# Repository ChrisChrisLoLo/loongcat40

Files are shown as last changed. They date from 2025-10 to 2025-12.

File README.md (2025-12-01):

# loongcat40
A 4x10 gasket mounted keyboard featuring a large OLED. A culmination of 5 years of learning.

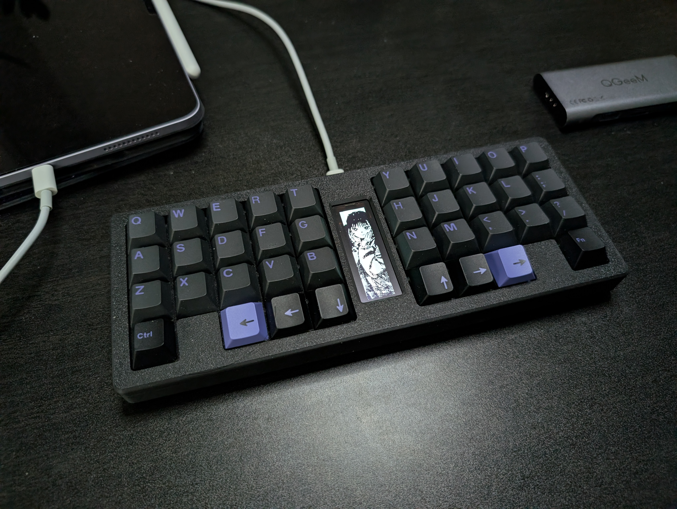
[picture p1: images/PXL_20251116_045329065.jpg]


## status
- v0.1 pcbs have been produced but not yet tested.
- v0.0 pcbs have been produced. v0.0 has been been tested.
  - The keyboard largely works, though GPIO20 requires an external pullup resistor. This may have been due to the rp2040 dev board I was using.

## about
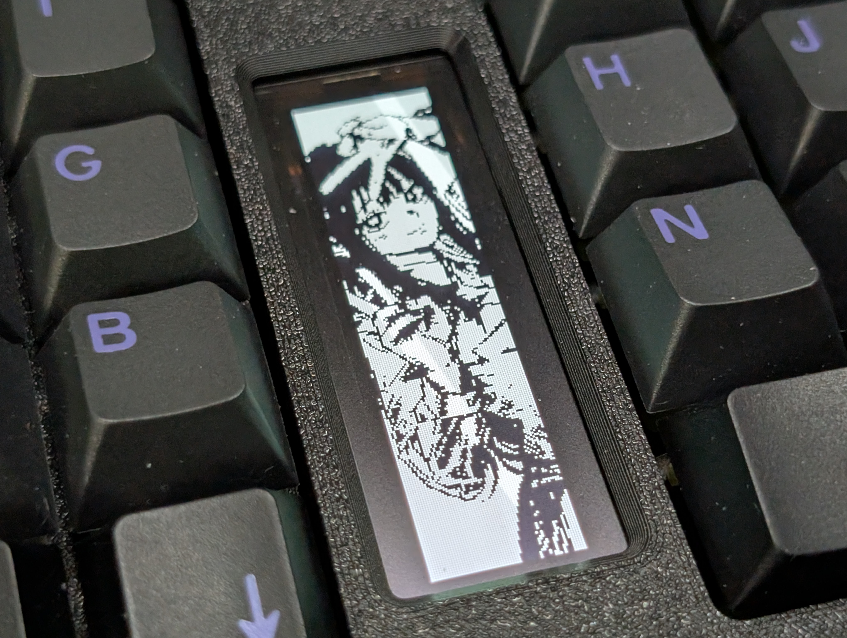
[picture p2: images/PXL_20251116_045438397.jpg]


## case
All of the case files you need can be found in the `case` directory.

## pcb
You can find the PCB source files in the `pcb` folder. The BOM files can be found in this folder.

## directory structure
- `case`
    You can find the files you need in this folder to print out a case for the keyboard
- `drafts`
    Stores any KLE or intermediate information used in making the case
- `pcb`
    Kicad project relating to the project

## BOM
- 1 PCB
- 40 hotswap sockets
- 40 diodes
- 1 2.08" OLED LCD (SH1122)
- 3mm poron gasket strips (80mm x 3mm x 4mm)
- 1 Raspberry Pi Pico 1
- 3D printed parts
  - 4 TPU oled standoffs
    - used to make sure that the oled is aligned when soldering
  - 2 PLA plates
  - 1 PLA case bottom
  - 1 PLA casetop
- 12 5mm M2 screws
- 4 rubber bumpons
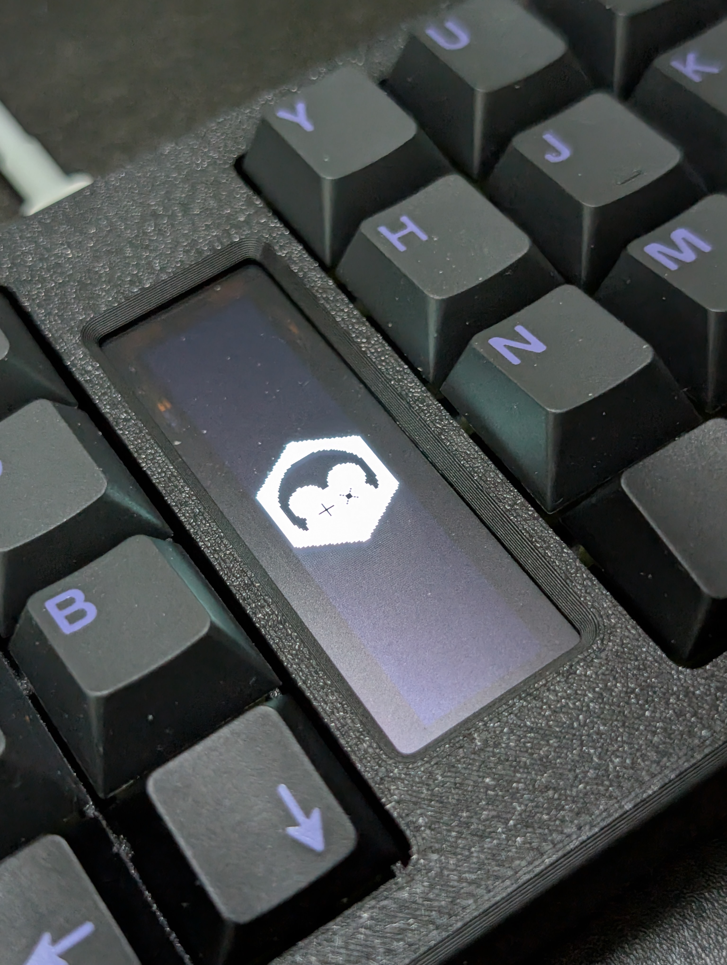
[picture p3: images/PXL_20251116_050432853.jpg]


## assembly
- Assemble the PCB without the oled
  - the Pico should be soldered via castellated pins. Male pin headers should _not_ be used 
- Put the 4 TPU oled standoffs onto the oled module. These standoffs will help align the oled
- Solder the oled to the pcb. The oled module should be on the other side of the board such that it's on the opposite side 
- Put the poron gaskets onto the plate
- Put the keys through the plate and onto the PCB
- Put the PCB onto the top of the case
- Put the bottom of the case on
- Screw in the bottom of the case
  - Note that screwing the screws for the first time may take some force, as the screws will be threading the plastic of the top
- Put bumpers on the bottom of the case
- Done!

## firmware
You can find the QMK firmware for this project here: https://github.com/ChrisChrisLoLo/qmk_firmware/tree/loongcat40

## acknowledgements

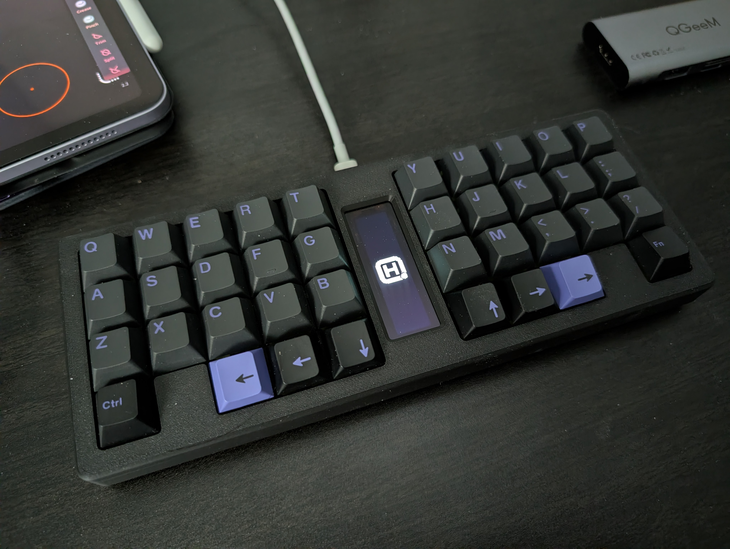
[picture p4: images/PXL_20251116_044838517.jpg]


Thank you to [NextPCB](https://www.nextpcb.com/?code=ChristianLo) and all of my Github Sponsors for sponsoring and supporting this project!

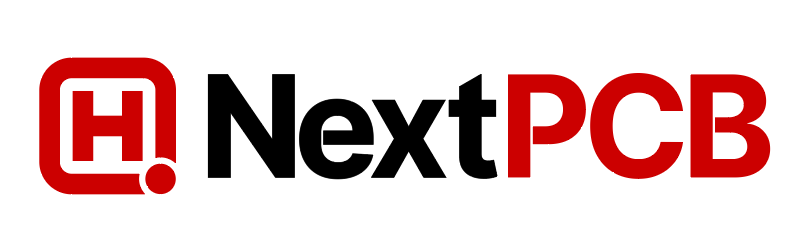
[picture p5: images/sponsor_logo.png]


Big thank you to [@suh_ga](https://x.com/suh_ga) for the fantastic artwork used and displayed on this keyboard! Please check her out at https://twitter.com/suh_ga!

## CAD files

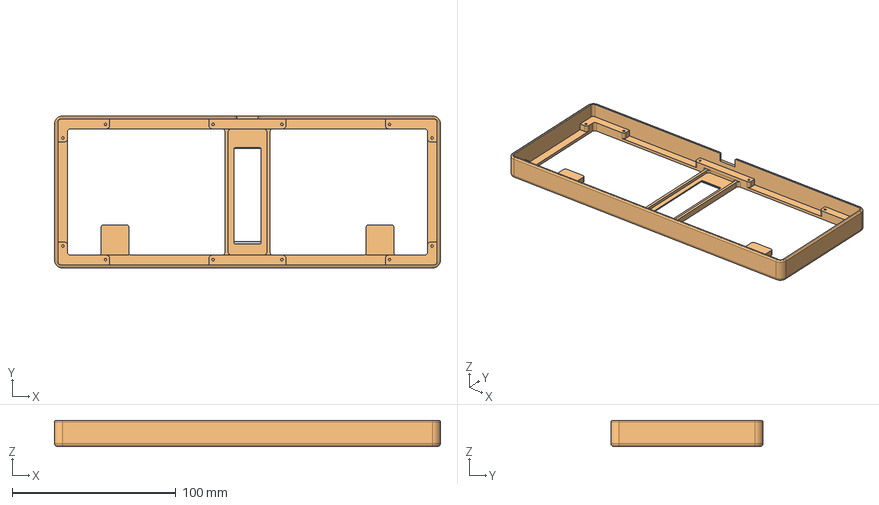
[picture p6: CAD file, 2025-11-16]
case/loongcat40.FCStd
235.9 x 93.0 x 16.0 mm
TopOledModCover
TopLcdModCover

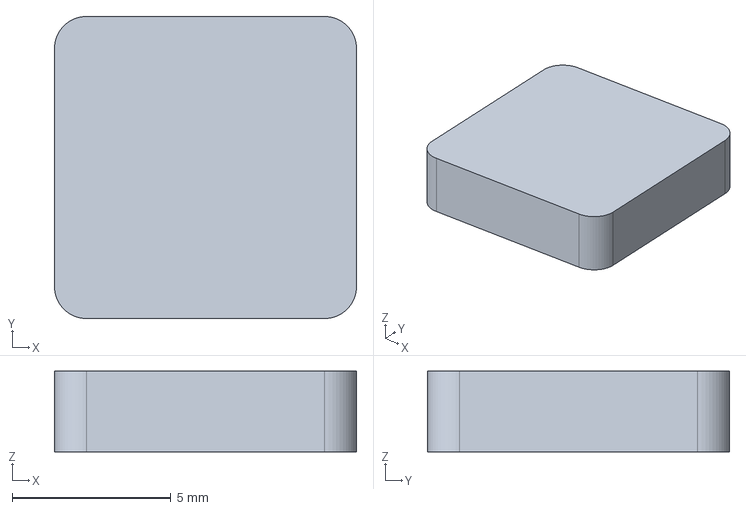
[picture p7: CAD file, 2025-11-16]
case/lcd_solder_jig_standoff.FCStd
9.50 x 9.50 x 2.54 mm

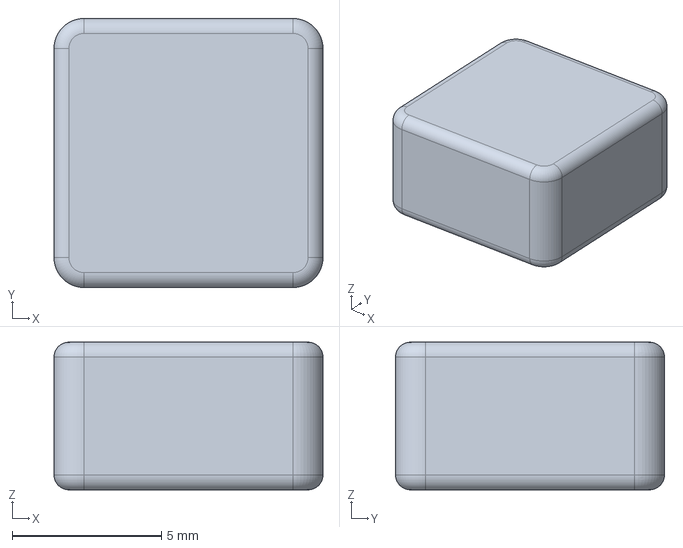
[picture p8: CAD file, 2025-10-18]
case/oled_standoff.FCStd
9.00 x 9.00 x 4.94 mm

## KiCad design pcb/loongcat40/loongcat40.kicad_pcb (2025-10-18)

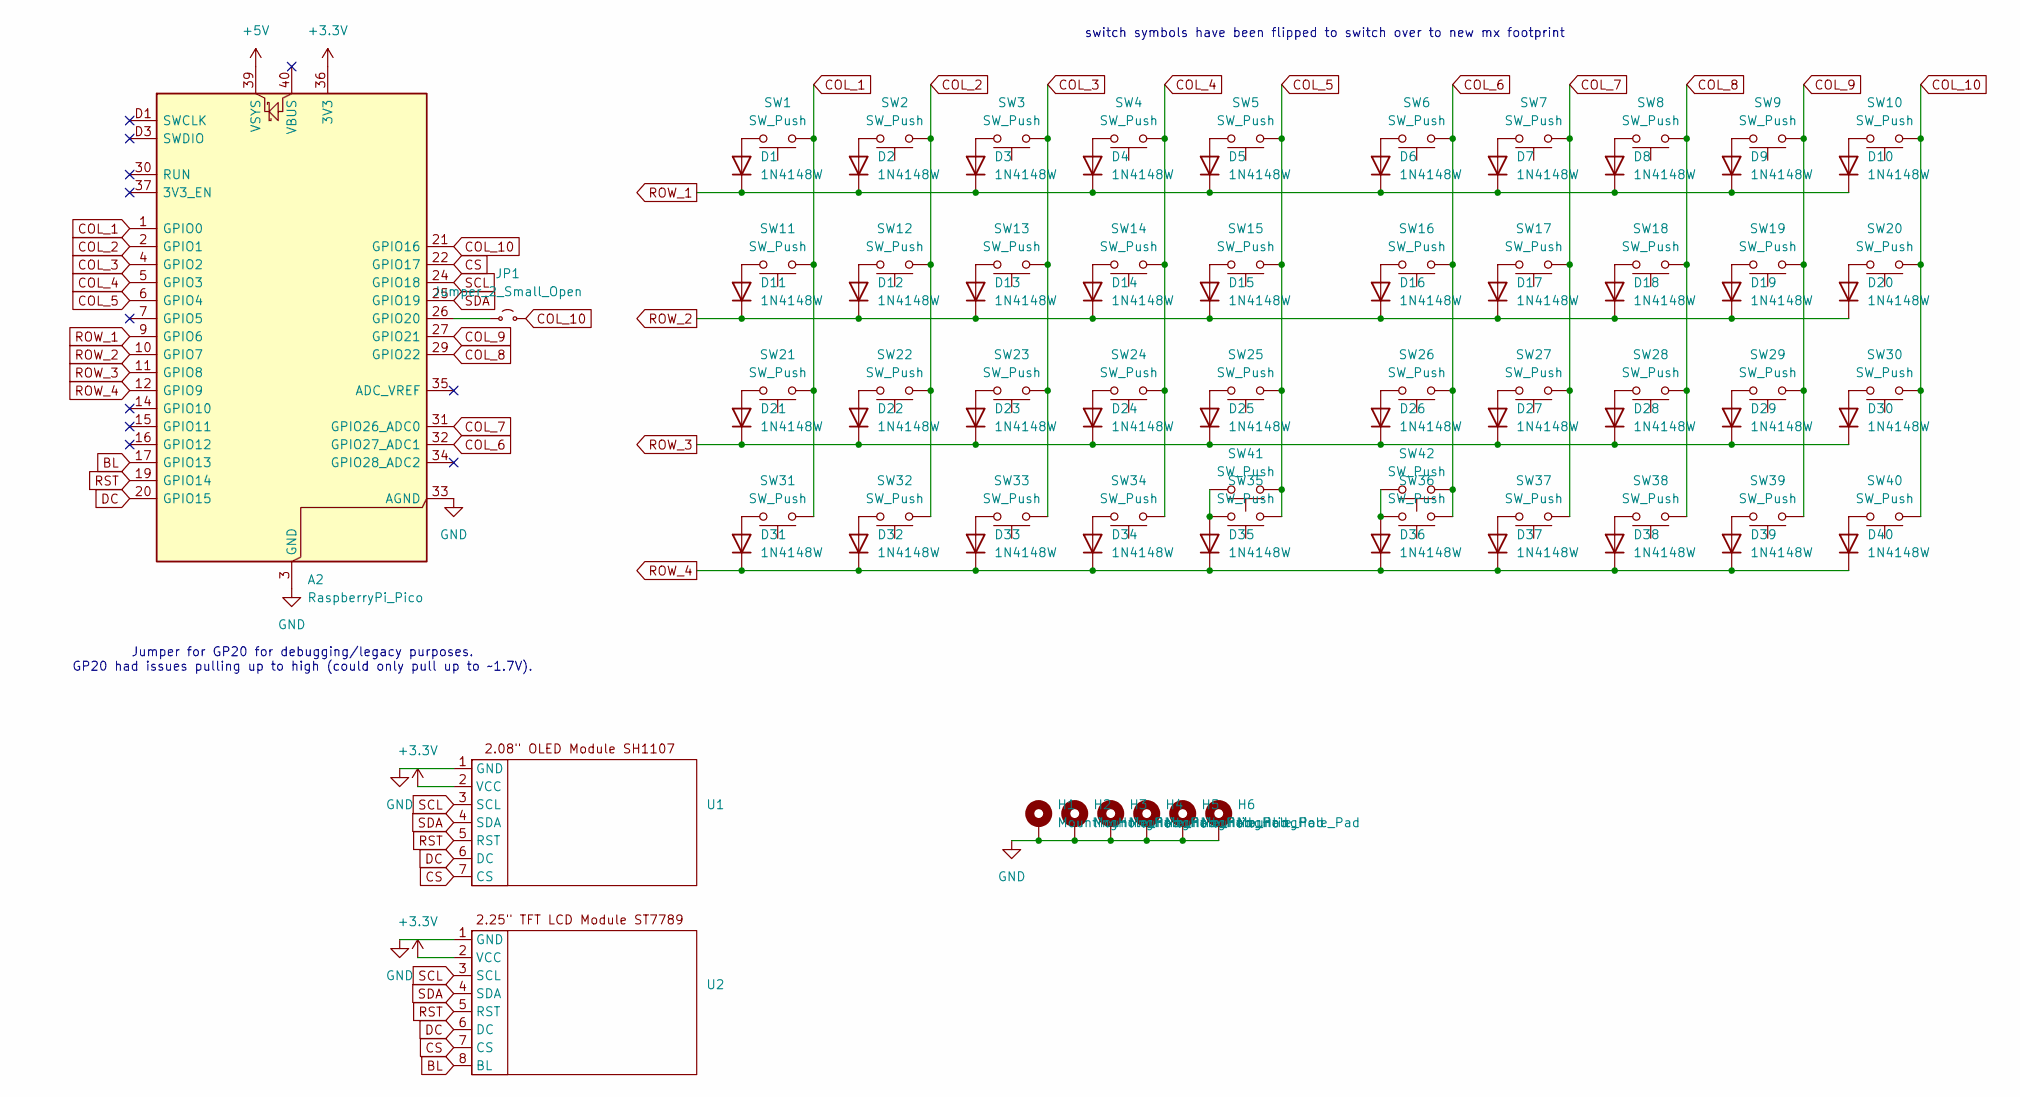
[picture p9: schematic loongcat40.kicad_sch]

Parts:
A2: RaspberryPi_Pico; RaspberryPi_Pico_Common_Unspecified
D1, D2, D3, D4, D5, D6, D7, D8, D9, D10, D11, D12, D13, D14, D15, D16, D17, D18, D19, D20, D21, D22, D23, D24, D25, D26, D27, D28, D29, D30, D31, D32, D33, D34, D35, D36, D37, D38, D39, D40: 1N4148W; D_SOD-123
H1, H2, H3, H4, H5, H6: MountingHole_Pad; MountingHole_2.2mm_M2_Pad
JP1: Jumper_2_Small_Open; SolderJumper-2_P1.3mm_Open_RoundedPad1.0x1.5mm
SW1, SW2, SW3, SW4, SW5, SW6, SW7, SW8, SW9, SW10, SW11, SW12, SW13, SW14, SW15, SW16, SW17, SW18, SW19, SW20, SW21, SW22, SW23, SW24, SW25, SW26, SW27, SW28, SW29, SW30, SW31, SW32, SW33, SW34, SW35, SW36, SW37, SW38, SW39, SW40, SW41, SW42: SW_Push; Kailh_socket_MX
U1: SH1122_2.08inch
U2: ST7789_2.25inch

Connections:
+3.3V: A2.36 (3V3), U1.2 (VCC), U2.2 (VCC)
+5V: A2.39 (VSYS)
BL: A2.17 (GPIO13), U2.8 (BL)
COL_1: A2.1 (GPIO0), SW1.1, SW11.1, SW21.1, SW31.1
COL_2: A2.2 (GPIO1), SW2.1, SW12.1, SW22.1, SW32.1
COL_3: A2.4 (GPIO2), SW3.1, SW13.1, SW23.1, SW33.1
COL_4: A2.5 (GPIO3), SW4.1, SW14.1, SW24.1, SW34.1
COL_5: A2.6 (GPIO4), SW5.1, SW15.1, SW25.1, SW35.1, SW41.1
COL_6: A2.32 (GPIO27_ADC1), SW6.1, SW16.1, SW26.1, SW36.1, SW42.1
COL_7: A2.31 (GPIO26_ADC0), SW7.1, SW17.1, SW27.1, SW37.1
COL_8: A2.29 (GPIO22), SW8.1, SW18.1, SW28.1, SW38.1
COL_9: A2.27 (GPIO21), SW9.1, SW19.1, SW29.1, SW39.1
COL_10: A2.21 (GPIO16), JP1.2 (B), SW10.1, SW20.1, SW30.1, SW40.1
CS: A2.22 (GPIO17), U1.7 (CS), U2.7 (CS)
DC: A2.20 (GPIO15), U1.6 (DC), U2.6 (DC)
GND: A2.3 (GND), A2.8 (GND), A2.13 (GND), A2.18 (GND), A2.23 (GND), A2.28 (GND), A2.33 (AGND), A2.38 (GND), A2.D2 (GND), H1.1, H2.1, H3.1, H4.1, H5.1, H6.1, U1.1 (GND), U2.1 (GND)
unnamed: A2.26 (GPIO20), JP1.1 (A)
unnamed: D1.2 (A), SW1.2
unnamed: D2.2 (A), SW2.2
unnamed: D3.2 (A), SW3.2
unnamed: D4.2 (A), SW4.2
unnamed: D5.2 (A), SW5.2
unnamed: D6.2 (A), SW6.2
unnamed: D7.2 (A), SW7.2
unnamed: D8.2 (A), SW8.2
unnamed: D9.2 (A), SW9.2
unnamed: D10.2 (A), SW10.2
unnamed: D11.2 (A), SW11.2
unnamed: D12.2 (A), SW12.2
unnamed: D13.2 (A), SW13.2
unnamed: D14.2 (A), SW14.2
unnamed: D15.2 (A), SW15.2
unnamed: D16.2 (A), SW16.2
unnamed: D17.2 (A), SW17.2
unnamed: D18.2 (A), SW18.2
unnamed: D19.2 (A), SW19.2
unnamed: D20.2 (A), SW20.2
unnamed: D21.2 (A), SW21.2
unnamed: D22.2 (A), SW22.2
unnamed: D23.2 (A), SW23.2
unnamed: D24.2 (A), SW24.2
unnamed: D25.2 (A), SW25.2
unnamed: D26.2 (A), SW26.2
unnamed: D27.2 (A), SW27.2
unnamed: D28.2 (A), SW28.2
unnamed: D29.2 (A), SW29.2
unnamed: D30.2 (A), SW30.2
unnamed: D31.2 (A), SW31.2
unnamed: D32.2 (A), SW32.2
unnamed: D33.2 (A), SW33.2
unnamed: D34.2 (A), SW34.2
unnamed: D35.2 (A), SW35.2, SW41.2
unnamed: D36.2 (A), SW36.2, SW42.2
unnamed: D37.2 (A), SW37.2
unnamed: D38.2 (A), SW38.2
unnamed: D39.2 (A), SW39.2
unnamed: D40.2 (A), SW40.2
ROW_1: A2.9 (GPIO6), D1.1 (K), D2.1 (K), D3.1 (K), D4.1 (K), D5.1 (K), D6.1 (K), D7.1 (K), D8.1 (K), D9.1 (K), D10.1 (K)
ROW_2: A2.10 (GPIO7), D11.1 (K), D12.1 (K), D13.1 (K), D14.1 (K), D15.1 (K), D16.1 (K), D17.1 (K), D18.1 (K), D19.1 (K), D20.1 (K)
ROW_3: A2.11 (GPIO8), D21.1 (K), D22.1 (K), D23.1 (K), D24.1 (K), D25.1 (K), D26.1 (K), D27.1 (K), D28.1 (K), D29.1 (K), D30.1 (K)
ROW_4: A2.12 (GPIO9), D31.1 (K), D32.1 (K), D33.1 (K), D34.1 (K), D35.1 (K), D36.1 (K), D37.1 (K), D38.1 (K), D39.1 (K), D40.1 (K)
RST: A2.19 (GPIO14), U1.5 (RST), U2.5 (RST)
SCL: A2.24 (GPIO18), U1.3 (SCL), U2.3 (SCL)
SDA: A2.25 (GPIO19), U1.4 (SDA), U2.4 (SDA)

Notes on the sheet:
Jumper for GP20 for debugging/legacy purposes. GP20 had issues pulling up to high (could only pull up to ~1.7V).
switch symbols have been flipped to switch over to new mx footprint

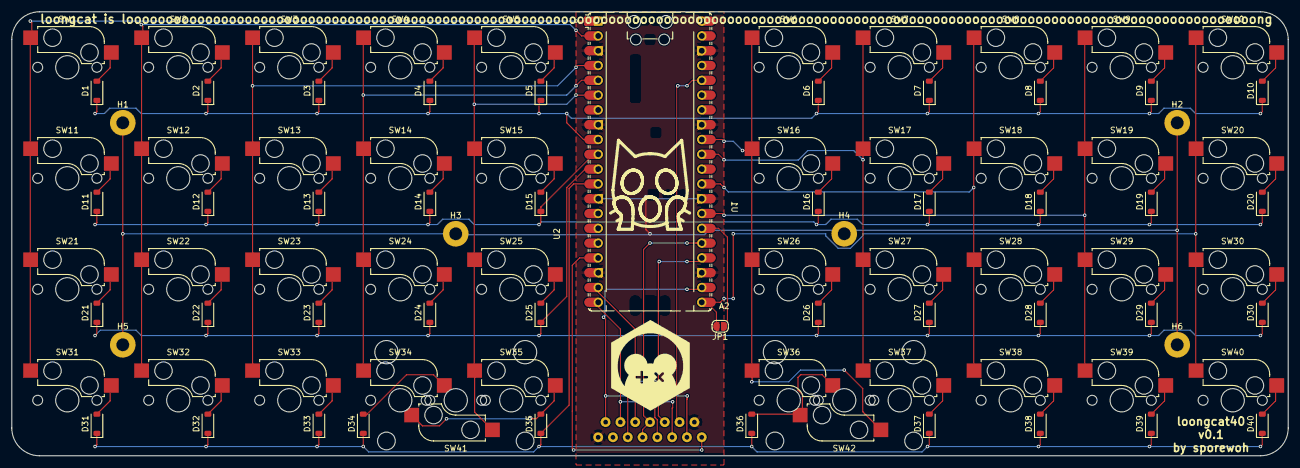
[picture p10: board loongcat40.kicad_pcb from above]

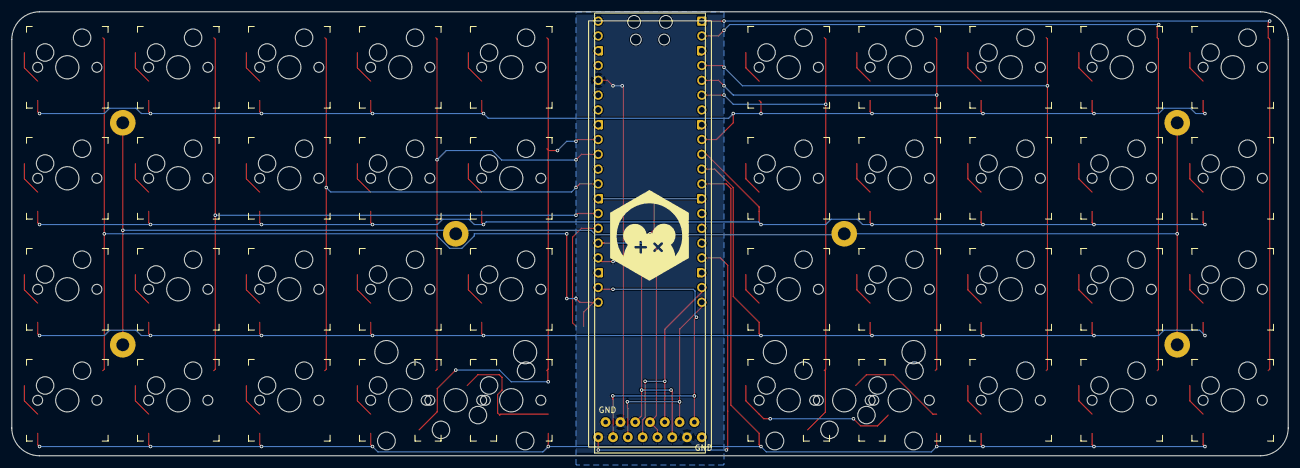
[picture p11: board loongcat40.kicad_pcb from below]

Board: 2 copper layers, 219.1 x 76.2 mm, 92 parts (43 on the bottom side), 63 nets.

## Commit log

2025-09-25 init pcb
    [loongcat40.kicad_pcb, loongcat40.kicad_sch]
2025-09-25 add kle; create init pcb design
    [loongcat40.kicad_pcb]
2025-09-26 position parts on pcb
    [loongcat40.kicad_pcb, loongcat40.kicad_sch]
2025-10-03 create outputs; init keyboard case
    [loongcat40-B_Cu.gbr, loongcat40-B_Mask.gbr, loongcat40-B_Paste.gbr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]
2025-10-05 add init case bottom
    [loongcat40.FCStd]
2025-10-05 add init base case top
    [loongcat40.FCStd]
2025-10-05 update pcb to v0.1
    [loongcat40.FCStd, loongcat40.kicad_pcb, loongcat40.kicad_sch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]
2025-10-05 add standoff
    [loongcat40.FCStd, oled_standoff.FCStd]
2025-10-06 update standoffs and case bottom
    [loongcat40.FCStd, oled_standoff.FCStd]
2025-10-06 tighten tolerances
    [loongcat40.FCStd]
2025-10-07 refine case and standoffs
    [loongcat40.FCStd, oled_standoff.FCStd]
2025-10-13 reduce ground plane
    [loongcat40.kicad_pcb]
2025-10-13 increase shroud length
    [loongcat40.FCStd]
2025-10-13 remove pcb outputs
    [loongcat40-B_Cu.gbr, loongcat40-B_Mask.gbr, loongcat40-B_Paste.gbr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]
2025-10-13 add lcd standoff length
    [loongcat40.FCStd, oled_standoff.FCStd]
2025-10-15 add oled mod cover top
    [loongcat40.FCStd]
2025-10-15 connect ground holes to pico
    [loongcat40.kicad_pcb]
2025-10-16 add soldering jig; init lcd top
    [lcd_solder_jig_standoff.FCStd, loongcat40.FCStd]
2025-10-18 update pcb to support 2U stabilizers, update col10 pin
    [loongcat40.kicad_pcb, loongcat40.kicad_sch]
2025-10-18 update lcd fillet; add lcd square standoff
    [lcd_solder_jig_standoff.FCStd, loongcat40.FCStd, oled_standoff.FCStd]
2025-11-16 update freecad models
    [lcd_solder_jig_standoff.FCStd, loongcat40.FCStd]
